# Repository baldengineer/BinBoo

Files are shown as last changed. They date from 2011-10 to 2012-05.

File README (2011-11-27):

This project is my first attempt to commit to GitHub.  The hardware files are for the PCB used on the controller board.  It was created in a hurry and came back with many mistakes.  All mistakes have been corrected on the schematic but the PCB needs more work.

The code is as commented as I can make it.

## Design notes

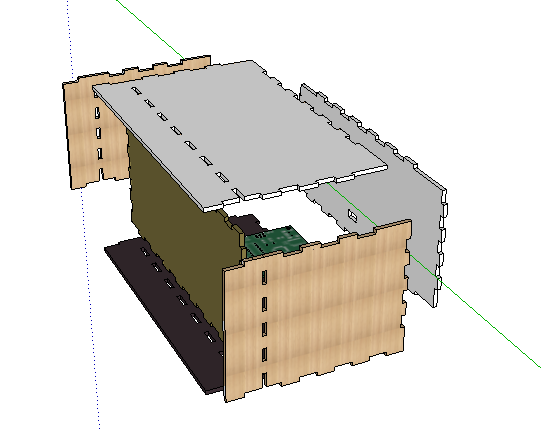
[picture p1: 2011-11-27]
Hardware/binboo-p2-exploded-screenshot.png

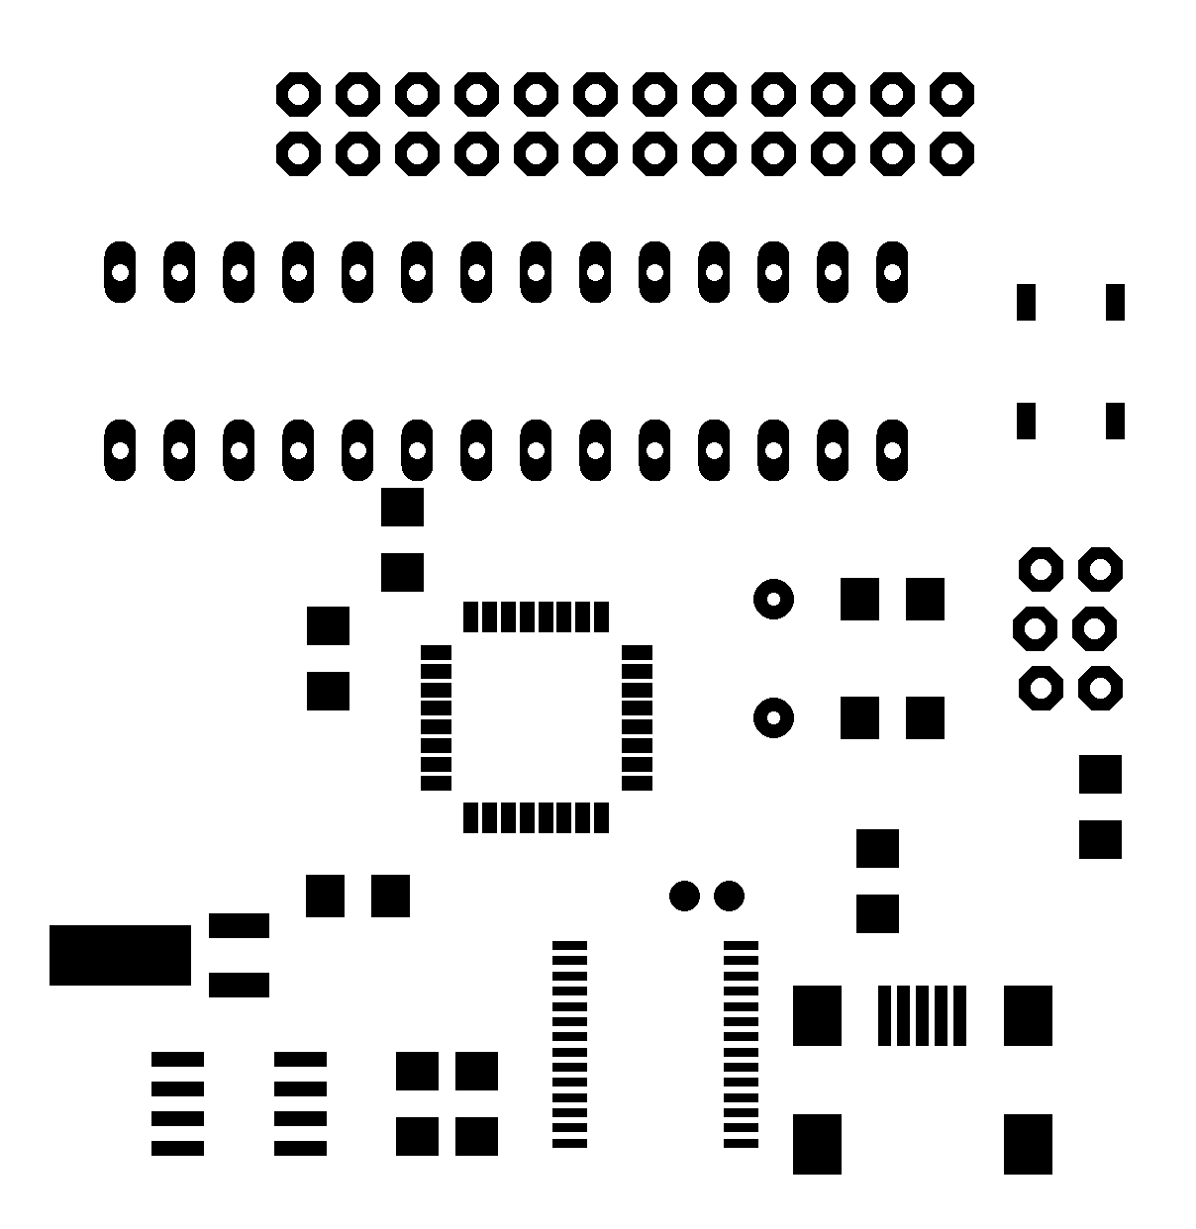
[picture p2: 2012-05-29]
Eagle/sketchup_images/eagle_binary_clock_rev1_top.png

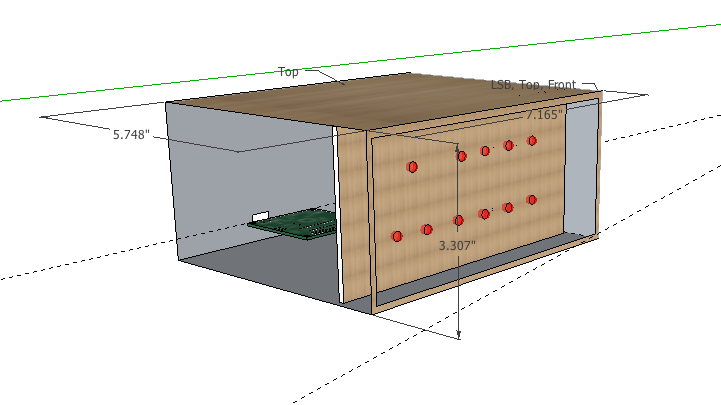
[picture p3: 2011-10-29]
Misc/binboo-rev1-sketch.png

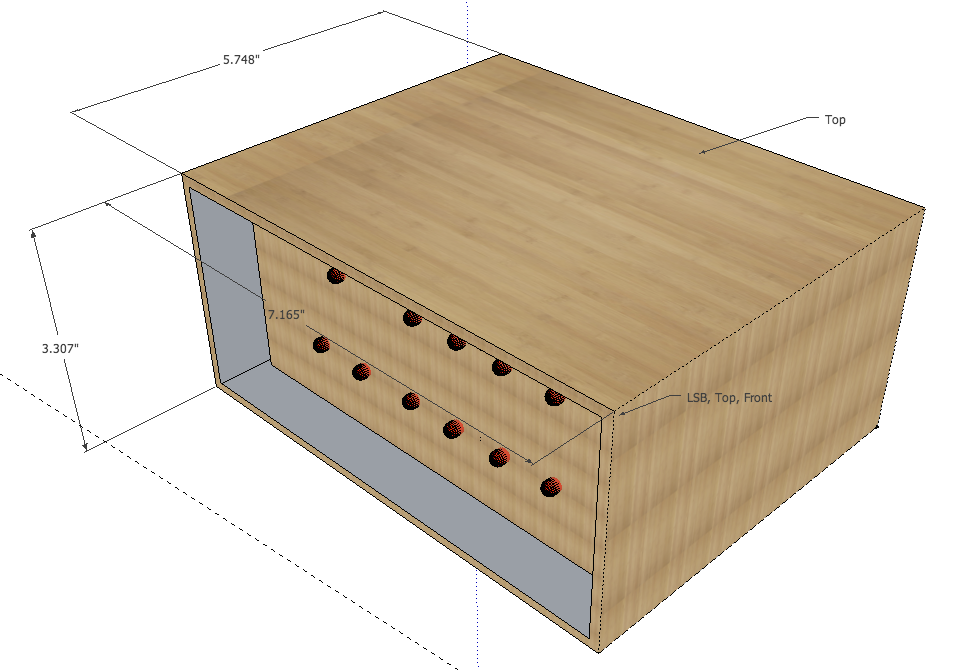
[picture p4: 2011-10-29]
Misc/binboo_sketchup_shot.png

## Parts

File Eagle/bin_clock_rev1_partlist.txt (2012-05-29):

Partlist

Exported from binary_clock_rev1.sch at 10/12/11 9:47 PM

EAGLE Version 5.11.0 Copyright (c) 1988-2010 CadSoft

Part     Value             Device                Package            Library   Sheet

BAT1                       BATTERY12MM           BATTCON_12MM       SparkFun  1
C1       100n              CAP1206               1206               SparkFun  1
C2       100n              CAP1206               1206               SparkFun  1
C3       100n              CAP1206               1206               SparkFun  1
C4       22pF              CAP1206               1206               JitterLab 1
C5       22pF              CAP1206               1206               JitterLab 1
C6       47uF              CPOL-USD/7343-31W     D/7343-31W         rcl       1
C7       47uF              CPOL-USD/7343-31W     D/7343-31W         rcl       1
IC1      ATMEGA168         ATMEGA168             TQFP32-08          SparkFun  1
JP1                        AVR_SPI_PRG_62X3_LOCK 2X3_LOCK           SparkFun  1
PTC                        RESISTOR1206          1206               SparkFun  1
R        TPB1,27           TPB1,27               B1,27              testpad   1
R1       4K7               RESISTOR1206          1206               JitterLab 1
R2       10k               RESISTOR1206          1206               SparkFun  1
R3       4k7               RESISTOR1206          1206               JitterLab 1
RREF     2.2k              RESISTOR1206          1206               JitterLab 1
R_BLK    10k               RESISTOR1206          1206               JitterLab 1
S1                         TAC_SWITCHSMD         TACTILE_SWITCH_SMD SparkFun  1
T        TPB1,27           TPB1,27               B1,27              testpad   1
U$1      DS1307SO8         DS1307SO8             SO08               SparkFun  1
U$2      M08X2             M08X2                 2X8                SparkFun  1
U$3      M04X2             M04X2                 2X4                SparkFun  1
U2       TLC5940TLC5940NT  TLC5940TLC5940NT      DIL28-3            TLC5940NT 1
U3       FT232RL-BASICSSOP FT232RL-BASICSSOP     SSOP28DB           SparkFun  1
X1       USBSMD            USBSMD                USB-MINIB          SparkFun  1
Y1       32kHz             CRYSTAL32-SMD         CRYSTAL-32KHZ-SMD  SparkFun  1
Y2       16MHz             CRYSTALHC49US         HC49US             SparkFun  1

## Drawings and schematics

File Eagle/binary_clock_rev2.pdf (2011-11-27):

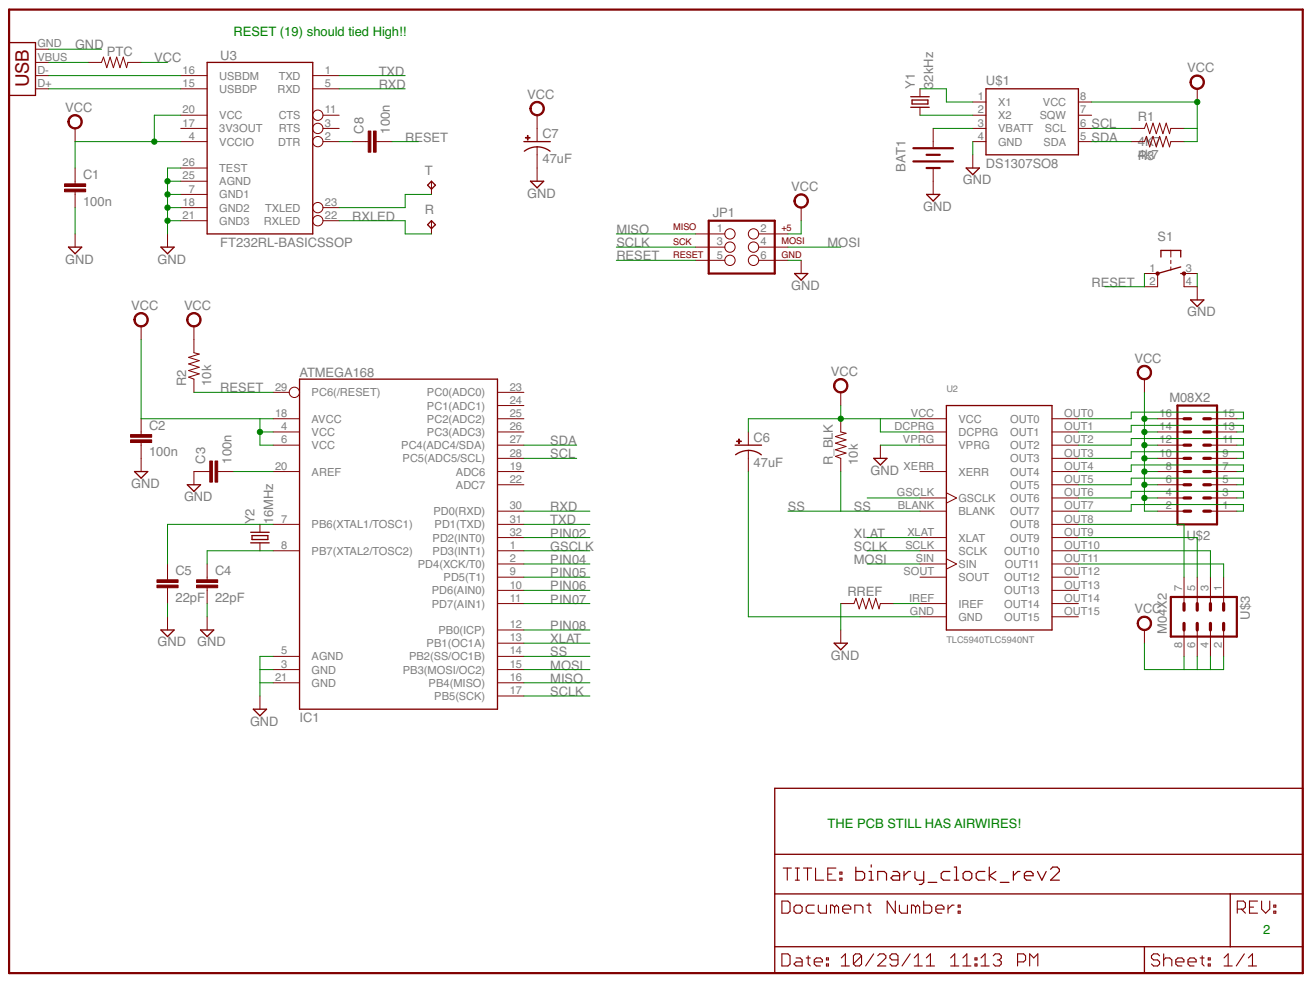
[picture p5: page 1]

RESET (19) should tied High!!

THE PCB STILL HAS AIRWIRES!

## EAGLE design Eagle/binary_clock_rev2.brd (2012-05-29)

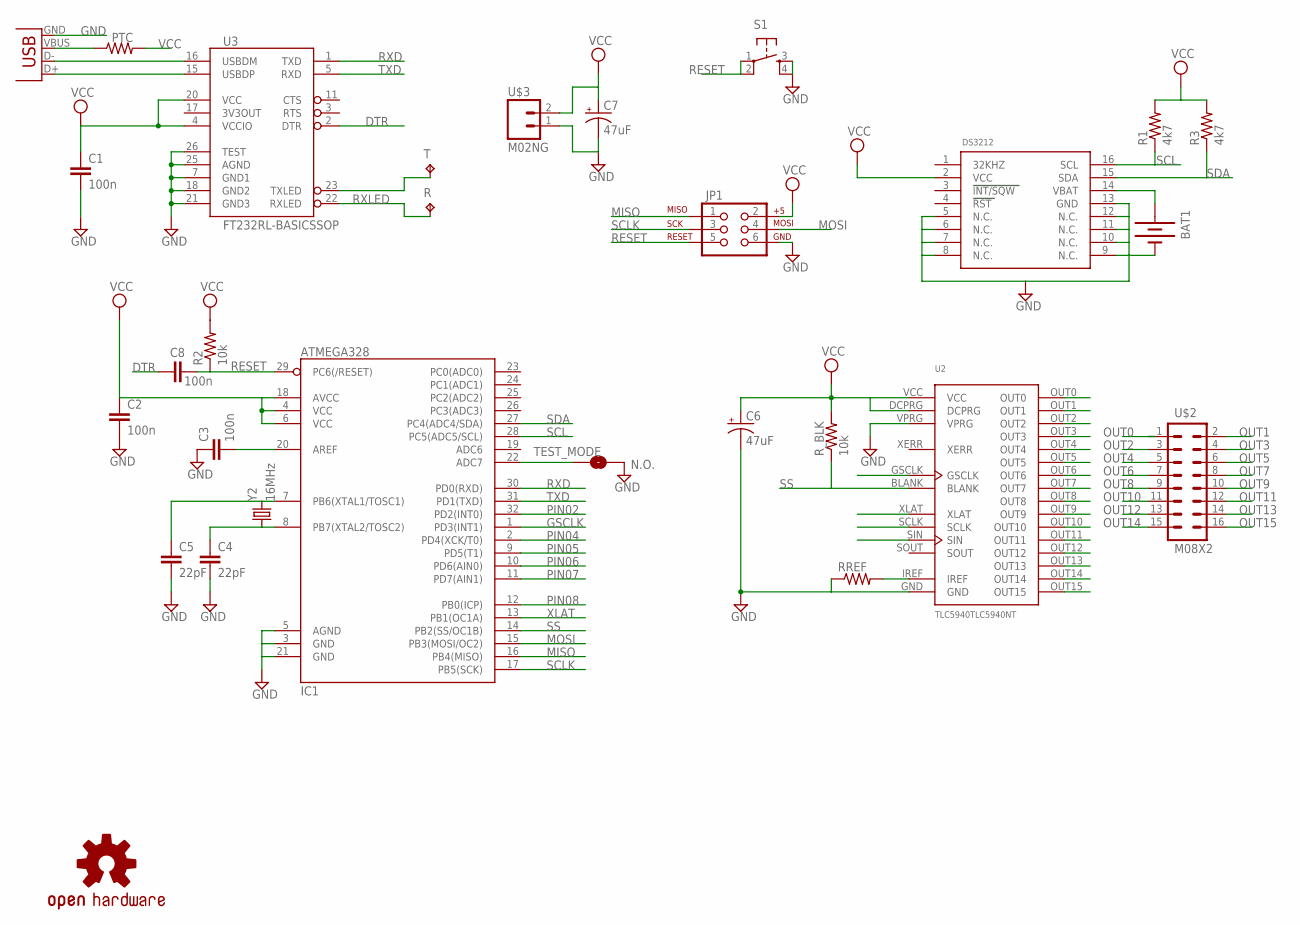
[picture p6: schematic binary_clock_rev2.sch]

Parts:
BAT1: BATTERY12MM; BATTCON_12MM
C1, C2, C3, C8: 100n; 1206
C4, C5: 22pF; 1206
C6, C7: 47uF; D/7343-31W
DS3212: DS3231; SO16L
IC1: ATMEGA328; TQFP32-08
JP1: AVR_SPI_PRG_62X3_LOCK; 2X3_LOCK
PTC: RESISTOR1206; 1206
R: TPB1,27; B1,27
R1, R3: 4k7; 1206
R2: 10k; 1206
RREF: 2.2k; 1206
R_BLK: 10k; 1206
S1: TAC_SWITCHSMD; TACTILE_SWITCH_SMD
T: TPB1,27; B1,27
TEST_MODE: N.O.; SJ_2S-NO
U2: TLC5940TLC5940NT; DIL28-3
U3: FT232RL-BASICSSOP; SSOP28DB
U$1: OSHW-LOGOM; OSHW-LOGO-M
U$2: M08X2; 2X8
U$3: M02NG; 1X02
X1: USBSMD; USB-MINIB
Y2: 16MHz; HC49US

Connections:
DTR: C8.1, U3.2 (DTR)
GND: BAT1.GND (-), C1.2, C2.2, C3.1, C4.2, C5.2, C6.-, C7.-, DS3212.5 (N.C.), DS3212.6 (N.C.), DS3212.7 (N.C.), DS3212.8 (N.C.), DS3212.9 (N.C.), DS3212.10 (N.C.), DS3212.11 (N.C.), DS3212.12 (N.C.), DS3212.13 (GND), IC1.3 (GND), IC1.5 (AGND), IC1.21 (GND), JP1.6, RREF.1, S1.3, S1.4, TEST_MODE.2, U2.GND, U2.VPRG, U3.7 (GND1), U3.18 (GND2), U3.21 (GND3), U3.25 (AGND), U3.26 (TEST), U$3.1, X1.GND
GSCLK: IC1.1 (PD3(INT1)), U2.GSCLK
MISO: IC1.16 (PB4(MISO)), JP1.1
MOSI: IC1.15 (PB3(MOSI/OC2)), JP1.4, U2.SIN
unnamed: IC1.22 (ADC7), TEST_MODE.1
unnamed: BAT1.PWR@2 (+), DS3212.14 (VBAT)
unnamed: U3.15 (USBDP), X1.D+
unnamed: U3.16 (USBDM), X1.D-
unnamed: C3.2, IC1.20 (AREF)
unnamed: PTC.1, X1.VBUS
unnamed: RREF.2, U2.IREF
unnamed: C5.1, IC1.7 (PB6(XTAL1/TOSC1)), Y2.2
unnamed: C4.1, IC1.8 (PB7(XTAL2/TOSC2)), Y2.1
OUT0: U2.OUT0, U$2.1
OUT1: U2.OUT1, U$2.2
OUT2: U2.OUT2, U$2.3
OUT3: U2.OUT3, U$2.4
OUT4: U2.OUT4, U$2.5
OUT5: U2.OUT5, U$2.6
OUT6: U2.OUT6, U$2.7
OUT7: U2.OUT7, U$2.8
OUT8: U2.OUT8, U$2.9
OUT9: U2.OUT9, U$2.10
OUT10: U2.OUT10, U$2.11
OUT11: U2.OUT11, U$2.12
OUT12: U2.OUT12, U$2.13
OUT13: U2.OUT13, U$2.14
OUT14: U2.OUT14, U$2.15
OUT15: U2.OUT15, U$2.16
PIN02: IC1.32 (PD2(INT0))
PIN04: IC1.2 (PD4(XCK/T0))
PIN05: IC1.9 (PD5(T1))
PIN06: IC1.10 (PD6(AIN0))
PIN07: IC1.11 (PD7(AIN1))
PIN08: IC1.12 (PB0(ICP))
RESET: C8.2, IC1.29 (PC6(/RESET)), JP1.5, R2.1, S1.1, S1.2
RXD: IC1.30 (PD0(RXD)), U3.1 (TXD)
RXLED: R.TP, U3.22 (RXLED)
SCL: DS3212.16 (SCL), IC1.28 (PC5(ADC5/SCL)), R1.1
SCLK: IC1.17 (PB5(SCK)), JP1.3, U2.SCLK
SDA: DS3212.15 (SDA), IC1.27 (PC4(ADC4/SDA)), R3.1
SS: IC1.14 (PB2(SS/OC1B)), R_BLK.1, U2.BLANK
TXD: IC1.31 (PD1(TXD)), U3.5 (RXD)
TXLED: T.TP, U3.23 (TXLED)
VCC: C1.1, C2.1, C6.+, C7.+, DS3212.2 (VCC), IC1.4 (VCC), IC1.6 (VCC), IC1.18 (AVCC), JP1.2, PTC.2, R1.2, R2.2, R3.2, R_BLK.2, U2.DCPRG, U2.VCC, U3.4 (VCCIO), U3.20 (VCC), U$3.2
XLAT: IC1.13 (PB1(OC1A)), U2.XLAT

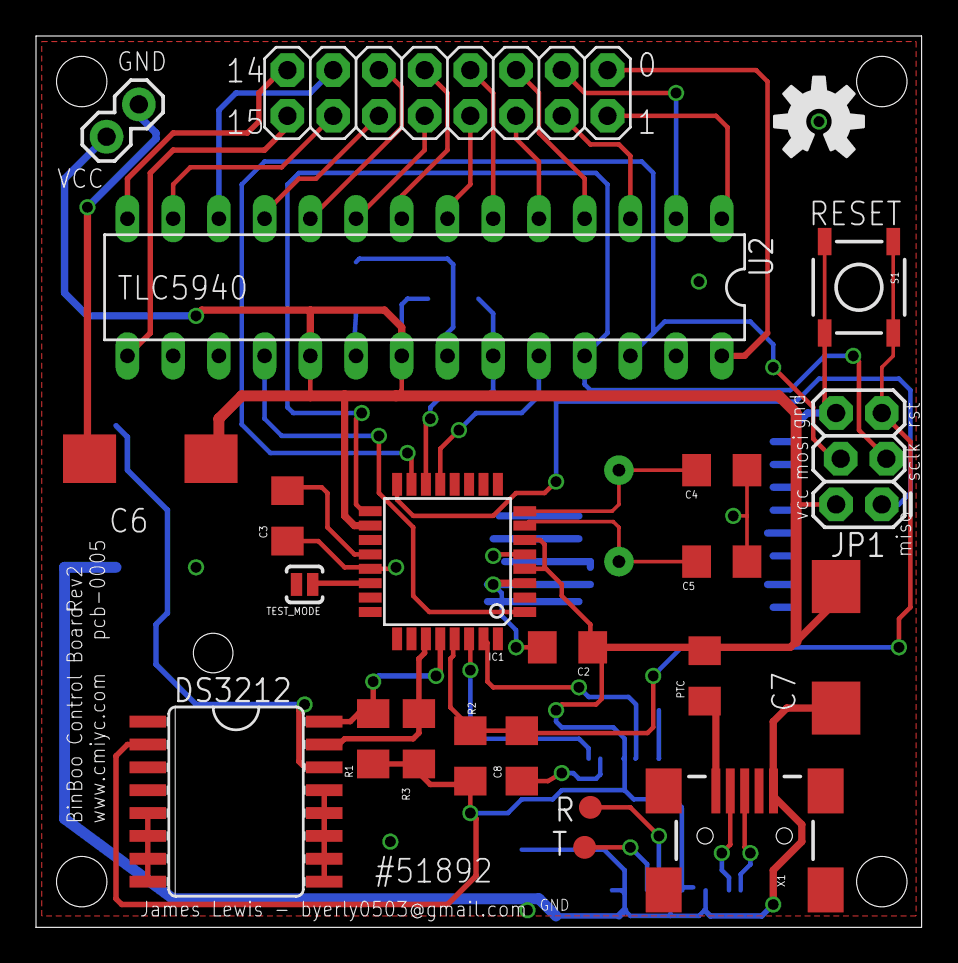
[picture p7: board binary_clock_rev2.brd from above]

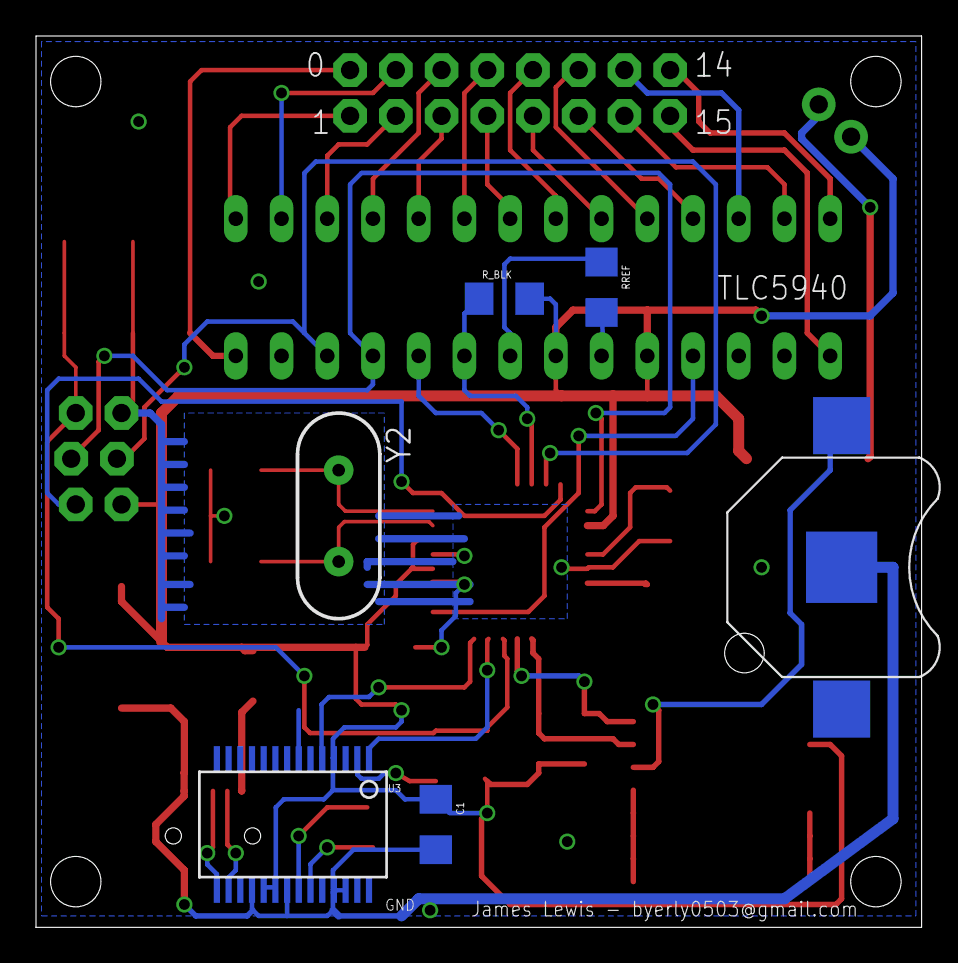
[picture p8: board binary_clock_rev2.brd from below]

Board: 2 copper layers, 49.2 x 49.5 mm, 29 parts (6 on the bottom side), 41 nets.

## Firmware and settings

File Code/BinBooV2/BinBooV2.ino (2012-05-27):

/*
 *
 *  BinBooV2
 *  Created by:  James C Lewis.  byerly0503@gmail.com 
 *  www.cmiyc.com
 *
 * BinBoo is a Binary clock made out of bamboo materials.  The electrical hardware includes
 * a ATmega328, DS1307 RTC, and a TLC5940.  These chips are connected to 11 LEDs.
 *
 * from bash:  date +%s (for number of seconds)
 * CDT offset: -18000
 * CST offset: -21600
 */
#include <Time.h>  
#include <Wire.h>  
#include <DS1307RTC.h> 
#include <Tlc5940.h>

#define EPOCH_OFFSET -18000
#define TIME_MSG_LEN   11
#define TIME_HEADER 'T'
#define TIME_REQUEST 7
#define WAIT_INTERVAL 5000

#define DAY_BRITE 512
#define NIGHT_BRITE 128

unsigned long waitMillis;

void setup() {
  Serial.begin(9600);
  Serial.println(F("BinBoo Release 0.2 - James Lewis (byerly0503@gmail.com)"));
  Serial.println(F("Use date +%s to get current time in seconds"));
  setSyncProvider(RTC.get);  // grab time from the RTC
  if(timeStatus()!= timeSet) 
    Serial.println("Unable to sync with the RTC");  // not really sure who is going to see this one.. ;)
  else
    Serial.println("RTC has set the system time");  

  Tlc.init();
  Tlc.clear();
  Tlc.update();

  waitMillis = millis() + 1000;   // setup first crossing point
  startUpSequence();
}

void loop() {
  int previousTime=0;
  int currentTime=0;
  while(1) {      // want to avoid making currentTime/previousTime global
    if (Serial.available())
      processSyncMessage();
    if ((long)(millis() - waitMillis) >= 0) {     // need to cast to signed math...
      printTimeDate();
      currentTime = calculateTimeBits();
       setTLCtime(previousTime, currentTime);
      previousTime = currentTime;
      waitMillis += WAIT_INTERVAL;  //sit around for another second.
    }
  }
}

void setTLCtime(int previousTime, int currentTime ) {

  if (previousTime == currentTime)    // time hasn't changed, so don't do anything
    return;

  int bright = 0;    // what is the max brightness, based on the time.
  if ((hour() >= 6) && (hour() <= 18))
    bright = DAY_BRITE;  
  else
    bright = NIGHT_BRITE;

  for (int i=0; i<=bright; i++) {
    int fadeAmount = 0;  // each look of the bright for, will be to fade up/down the leds
    for (int j=0; j<12; j++) {   // this loop determines which direction and intensity of fade
      switch (bitRead(previousTime, j) - bitRead(currentTime,j)) {
      case 0:  // no change, the led alone
        if bitRead(currentTime,j)
          fadeAmount = bright;
        else
          fadeAmount = 0;
        break;
      case -1: // turn the led on
        fadeAmount = i;
        break;
      case 1: // turn the led off
        fadeAmount = bright - i;
        break;
      }
      Tlc.set(j, fadeAmount);
    }   
    Tlc.update();
    delay(1);
  }
}



int calculateTimeBits() {
  int hours = hourFormat12();
  int minutes = minute();
  int timeLEDs=0;

  timeLEDs = hours;
  timeLEDs = hours << 8;

  timeLEDs += (minutes/10)<<4;
  timeLEDs += minutes%10;
  
  if (isPM())
    bitSet(timeLEDs, 11);

  return timeLEDs;
}

void printTimeDate() {
  printTime();
  Serial.print(" ");
  printDate();
  Serial.println("");
}

void printTime() {
  Serial.print(hourFormat12());
  printDigits(minute());
  printDigits(second());
  Serial.print(" ");
  if (isAM())
    Serial.print("AM");
  else
    Serial.print("PM");
}

void printDate() {
  Serial.print(month());
  Serial.print("/");
  Serial.print(day());
  Serial.print("/");
  Serial.print(year()); 
}

void printDigits(int digits){
  // utility function for digital clock display: prints preceding colon and leading 0
  Serial.print(":");
  if(digits < 10)
    Serial.print('0');
  Serial.print(digits);
}


void startUpSequence() {
  for (int j=0; j<12; j++) {
    Tlc.clear();
    for (int i=0; i<(DAY_BRITE+1); i=i+32) {
      Tlc.set(j, i);
      Tlc.update();
      delay(10);
    }
    for (int i=DAY_BRITE; i > 0; i=i-32) {
      Tlc.set(j,i);
      Tlc.update();
      delay(10);
    }

  }
}


void processSyncMessage() {
  // if time sync available from serial port, update time and return true
  if (Serial.available() >=  TIME_MSG_LEN ) {  // time message consists of a header and ten ascii digits
    char c = Serial.read() ; 

    if( c == TIME_HEADER ) {       
      Serial.print(c);  
      time_t pctime = 0;
      for(int i=0; i < TIME_MSG_LEN -1; i++){   
        c = Serial.read();          
        if( c >= '0' && c <= '9'){   
          pctime = (10 * pctime) + (c - '0'); // convert digits to a number    
        }
      }   
      pctime = pctime EPOCH_OFFSET;  // the define has a math sign in it
      Serial.print(" - ");
      Serial.println(pctime);
      RTC.set(pctime);
      setTime(pctime);   // Sync Arduino clock to the time received on the serial port
      waitMillis += 100;
    }  
  }
}

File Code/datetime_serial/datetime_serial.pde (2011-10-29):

void setup() {
 pinMode(13, OUTPUT); 
 Serial.begin(9600);
 Serial.print("Date: ");
 Serial.println(__DATE__); 
  Serial.print("Time: "); 
  Serial.println(__TIME__); 
  Serial.println();
  Serial.println();
}

void loop() {
 Serial.println(__TIME__);
 digitalWrite(13, !digitalRead(13));
 delay(500); 
}

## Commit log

2011-10-29 Initial Commit
    Each direction contains the appropriate files for either the firmware,
    the pcb, or the enclosure.
    [binary_clock_rev1.brd, binary_clock_rev1.sch]
2011-10-30 Schematic Fixes and First Code Commit
    Schematic needed significant changes. The FTDI isn't wired correctly,
    nor is the TLC5940. The TLC has missing VCC/GND connections. More
    problematic is that the "GND" bar for the LEDs is completely wrong.
    The TLC sinks current, not sources it (duh).
    [binary_clock_rev1.brd, binary_clock_rev1.sch, binary_clock_rev2.brd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]
2011-11-05 Smooth fading for time changes.
    Added some code to smoothly fade the LEDs on/off as the time changes.
    Subtle effect but takes away from the stark "on" then "off."
2011-11-27 Major box update
    None of the pieces from rev1 work. This is a completely re-worked
    version. All pieces that are cut by ponoko have been turned into
    Components in Google Sketchup.
2012-05-27 BCD Version of the code
    This code now expected 4 columns with 4 LEDs to represent a BCD of the
    time.
2012-05-29 Replaced DS1307 with a DS3212 and other fixes.
    Schematic Changes:
    * Added solderable-jumper (n.o.) on ATmega328, ADC7 to enable "test
    mode"
    * Fixed errors on FT232R:
    * tied reset to VCC (on PCB only)
    * Swapped TX and RX (so that they are crossed going into
    ATmega328)
    * Removed DS1307 Circuit Completely
    * Fixed Errors on TLC5940:
    * Tied VPRG to GND
    * Tied DCPRG to VCC
    * Cleaned up IREF and R_BLK
    * Completely re-laid out how LEDs are attached (completely wrong
    on rev1)
    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
    [binary_clock_rev1.brd, binary_clock_rev1.sch, binary_clock_rev2.brd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]
